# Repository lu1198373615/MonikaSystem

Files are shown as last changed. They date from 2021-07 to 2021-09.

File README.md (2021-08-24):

# 【原创新型】可以与树莓派合体的FPGA开发板
原因GitHub卡顿太严重。所以这个仓库已经搬到gitee了     
请前往[同名Gitee仓库](https://gitee.com/lu1198373615/MonikaSystem) 查看最新版       
想要板子的话可以直接拿gerber文件夹光绘文件打样，但开发板为本仓库创建者原创，仅供大家学习和交流，转载请注明出处。       
## 写在前面
树莓派拥有全球最大的开源硬件社区；FPGA逻辑资源丰富、IO众多且设计灵活；而高速AD和高速DA是实现信号发生器、示波器和软件无线电系统不可缺少的基本器件。
然而，树莓派社区缺少兼容性较好的FPGA开发板；此外，树莓派采用非实时操作系统，无法为高速AD、高速DA提供时钟驱动；
针对这些问题，本仓库开源一种新颖的配置了高速AD和高速DA的FPGA开发板，板上40pin扩展口可以与树莓派4b完美兼容，单板成本￥300左右。   
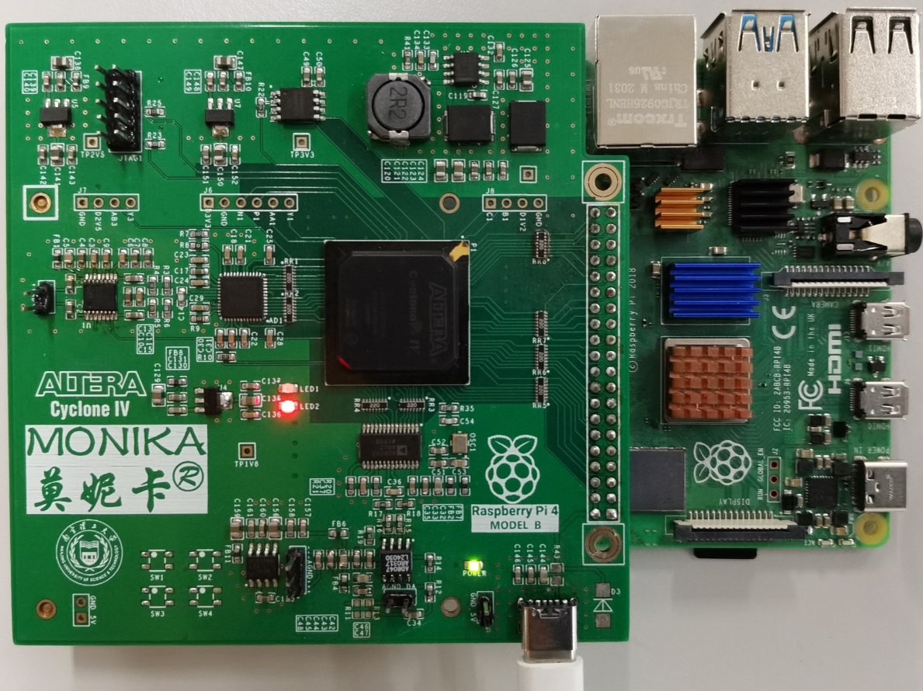
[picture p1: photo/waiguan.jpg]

    
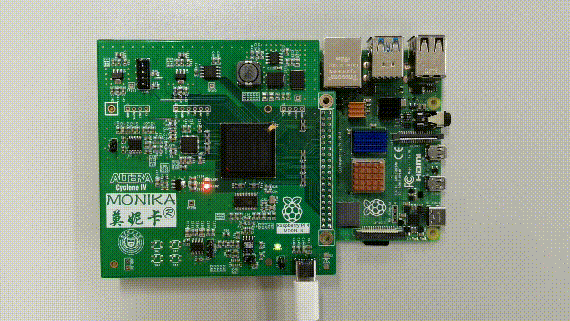
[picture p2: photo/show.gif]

    
## 介绍视频
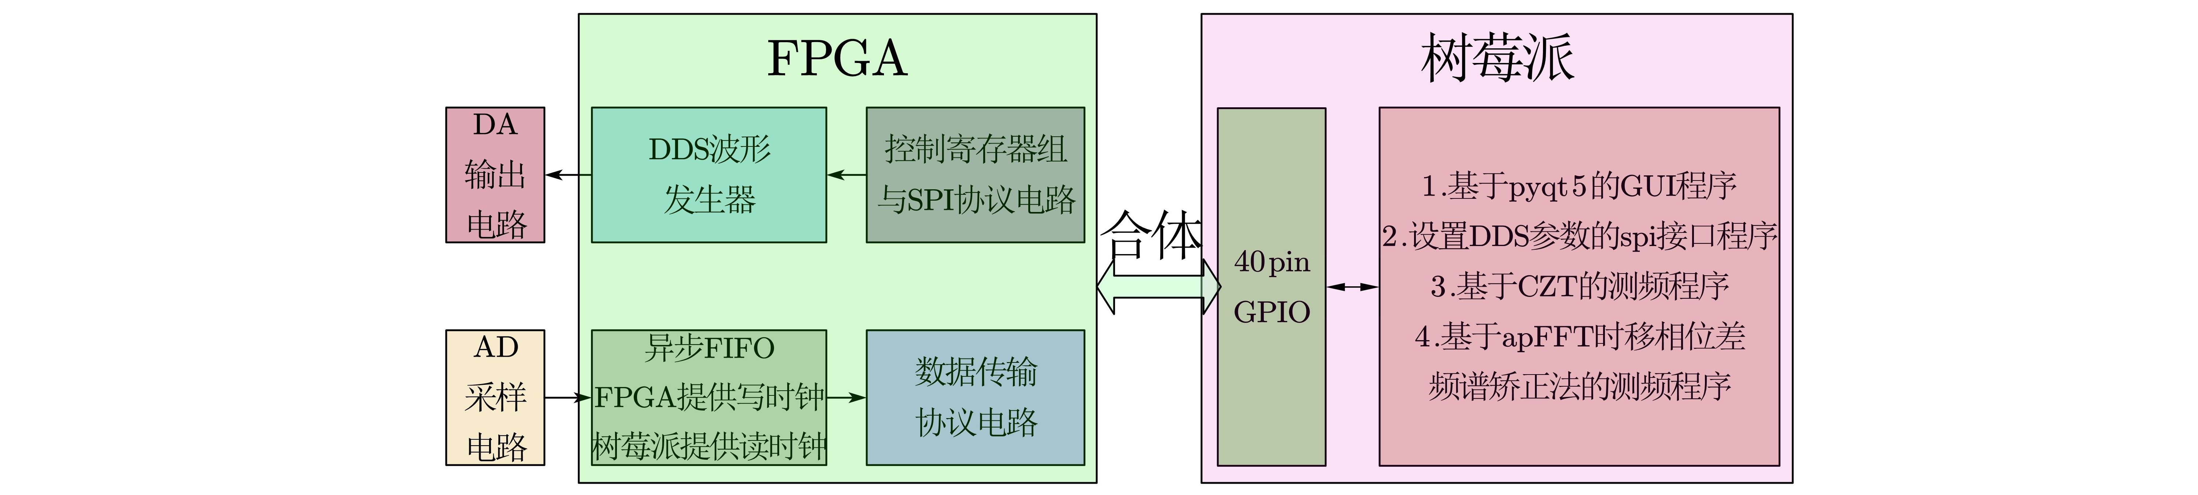
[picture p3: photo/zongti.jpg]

    
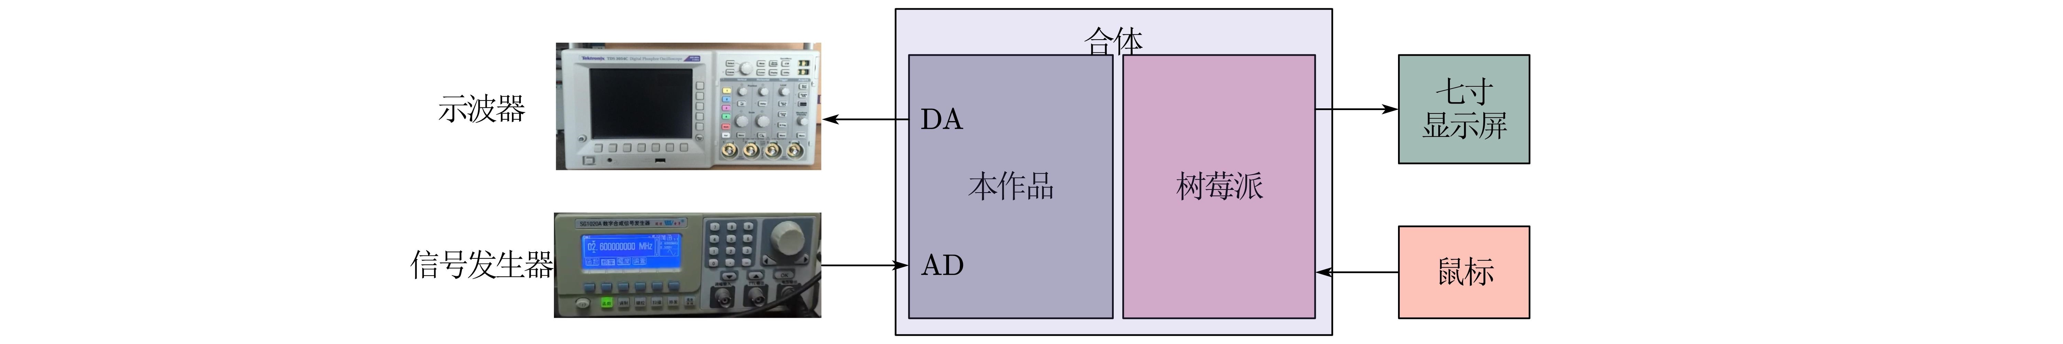
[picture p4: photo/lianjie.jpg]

    
鄙人把[介绍视频](https://www.bilibili.com/video/BV1644y1q7s1/) 放在了B站。     
视频拍摄场景：把本作品和树莓派合体后，DA输出端连接示波器，AD输入端接信号发生器，如上图所示。
用鼠标操作运行在树莓派的基于pyqt5的GUI程序，可以随意改变DA输出的波形，可以对信号发生器送入AD的信号进行显示和频率测量。     
## 工具与依赖项
+ 电路板制作      
Cadence套件：使用OrCAD绘制原理图、使用Allegro绘制PCB     
焊接时采用钢网刷锡和回流焊机     
+ FPGA端程序设计       
Altera公司工具：Quartus Primer 17.1、Modelsim-Altera、SignalTab等       
+ 树莓派端程序设计      
Python 3.x，用到的pypi库包括但不限于`pyqt5`、`matplotlib`、`numpy`       
操作GPIO用的是`wiringPi-Python`包，底层的`wiringpi.c`文件需要稍作修改：[修改说明](https://github.com/lu1198373615/MonikaSystem/blob/master/MODIFY.md)。
## 技术介绍
+ [硬件篇--自制FPGA开发板介绍](https://github.com/lu1198373615/MonikaSystem/blob/master/HARDWARE.MD)   
_（↑↑↑点击标题可查看↑↑↑）_    
_（这一部分依次讲解了外形尺寸设计、芯片选型原理图设计、电路板制作与测试。在芯片选型与原理图设计部分主要讲解了FPGA、电源、ADC和DAC电路，电源着重介绍DCDC电感电容值选型公式，ADC电路介绍差分放大器到ADC间共模电压的添加方式。电路板在深圳嘉立创完成打样，在学校实验室完成焊接和测试。约3500字，共20张图。）_    
+ [软件篇--“所见即所得”的任意波形发生器设计](https://github.com/lu1198373615/MonikaSystem/blob/master/SIGNALGENERATOR.md)    
_（↑↑↑点击标题可查看↑↑↑）_    
_（已经写完了，内容主要包括通过gif图片来展示程序功能，并描述如何利用DDS和SPI来实现这些功能。约1300字，13张图。）_    
+ [软件篇--示波器设计与频率测量算法](https://github.com/lu1198373615/MonikaSystem/blob/master/OSCILLOSCOPE.md)    
_（已经写完了，本部分展示了波形显示和频率测量的效果图，并介绍原理和实现方法。约1100字，共24图。）_    
+ 以上的信号发生器和示波器功能只是本开发板的示例程序，如果您有好的创意，欢迎补充：可以提issue，也可以直接在下方评论。     
_（期待您的程序为本开发板增加功能哦(づ￣ 3￣)づ）_     

## 附录

+ [小测试--树莓派4B使用wiringpi操作GPIO的速度](https://github.com/lu1198373615/MonikaSystem/blob/master/time_of_wiringpi.md)    

# 完结，撒花~~~

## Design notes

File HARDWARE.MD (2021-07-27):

## 序言
这一部分依次讲解了外形尺寸设计、芯片选型与原理图设计、电路板制作与测试。
在芯片选型与原理图设计部分主要讲解了FPGA、电源、AD和DA电路，电源着重介绍DCDC电感电容值选型公式，ADC电路介绍差分放大器到ADC间共模电压的添加方式。
电路板在深圳嘉立创完成打样，在学校实验室完成焊接和测试。约3500字，共20张图。     
## 外形尺寸设计
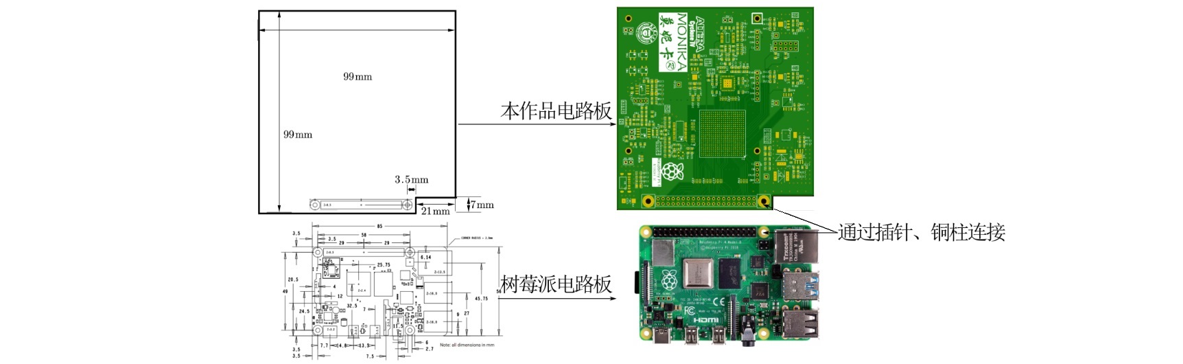
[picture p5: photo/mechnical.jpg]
   
    
电路板外形尺寸设计如上图。   
本作品设计初衷是为树莓派配套FPGA开发板，因此应预留40pin IO口与树莓派连接。   
大多数PCB打样厂家，单板边长100mm是价格的分水岭：
捷多邦99\*99mm的四层板是￥200/10pcs，而101\*101mm的四层板是￥439/10pcs；
华秋电路99\*99mm的四层板是￥199/10pcs，而101\*101mm的四层板是￥370/10pcs；
深圳嘉立创99\*99mm的四层板是￥80/10pcs，而101\*101mm的四层板是￥271.4/10pcs；
（价格查询时间：2021年6月20日晚上）。
因此本作品主体是99mm的正方形，这样可以享受最大的性价比。   
此外，本作品设计之初就考虑到树莓派4b的以太网口可能会挡到插针的连接，因此留了个7\*21mm的缺口。
（以太网：？？？我挡路了？？？）   

## 芯片选型与原理图设计
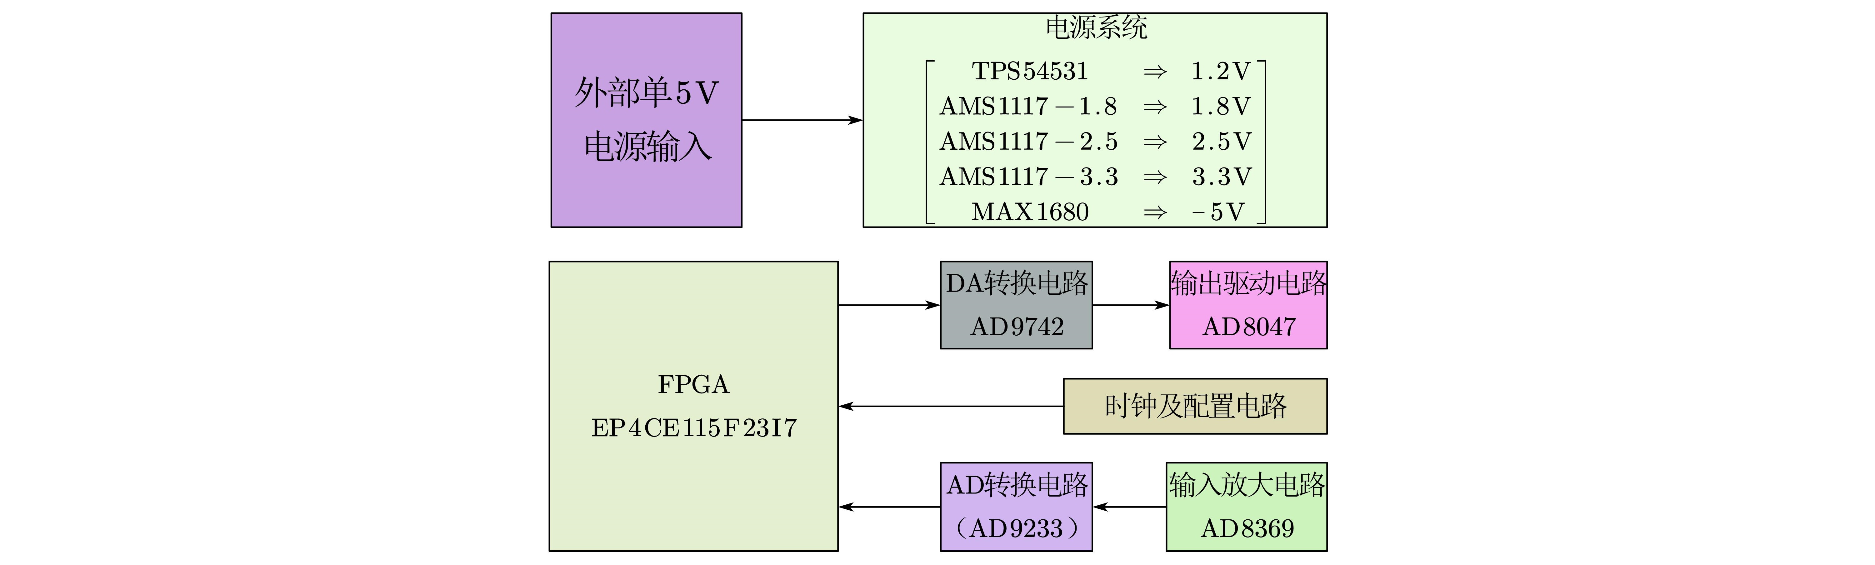
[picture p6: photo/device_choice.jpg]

    
### FPGA选型与设计
FPGA刚问世时价格昂贵，但近年来逐渐平民化。
其中，论性价比当吹Altera Cyclone IV E系列的EP4CE115F23I7N芯片，其资源如下：   
|  Logic elements (LEs)  |  Embedded memory  |  Embedded 18 × 18 multipliers  |  General-purpose PLLs  |  Global Clock Networks  |  User I/O Banks |  Maximum user I/O |
|  :----:  |  :----:  |  :----:  |  :----:  |  :----:  |  :----:  |  :----:  |
|  114480  |  3888  |  266  |  4  |  20  |  8  |  528  |

目前，桃bao店“深圳市叶恒科技”该芯片售价仅￥110（2021年6月20日晚上看是￥110，我记得前段时间看还是￥95来着，看来最近芯片确实都在涨价）。   
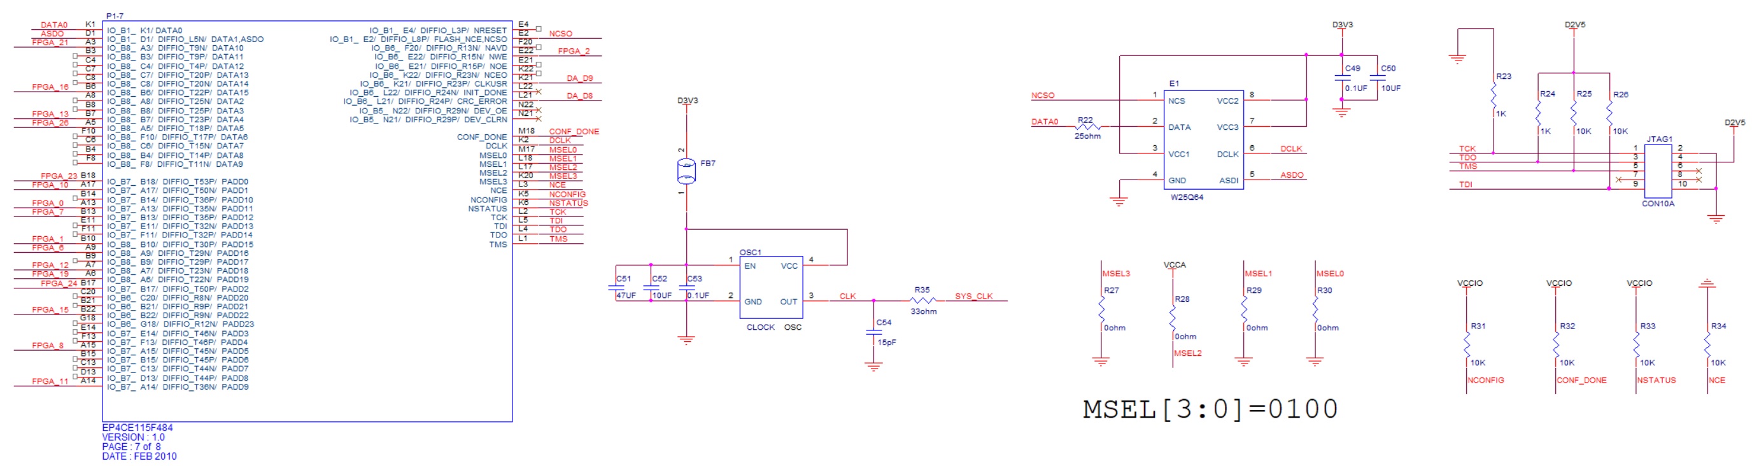
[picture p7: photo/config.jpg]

    
上图是FPGA的JTAG下载电路、FPGA配置电路以及时钟晶振电路，配置用的SPI_FLASH选用winbond公司的W25Q64芯片。   
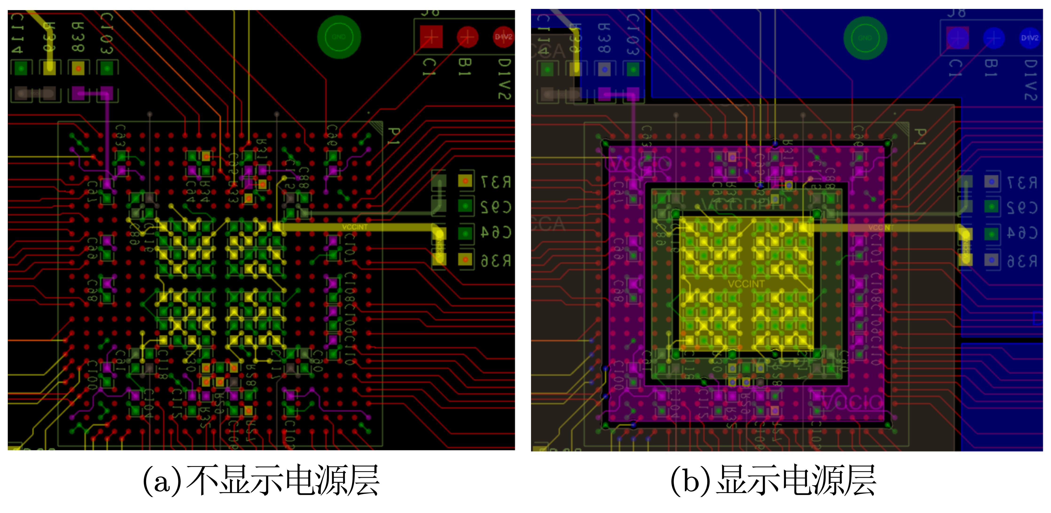
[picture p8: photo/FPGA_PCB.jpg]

    
上图是FPGA的layout部分，通过0&ohm;电阻对FPGA馈电有利于电路板调试；通孔打在去耦电容焊盘上，去耦电容全部放在电路板背面，有利于最小化EMI。
FPGA背面的0402电容的两焊盘间距0.5mm，FPGA的bga484封装焊盘间距也是0.5mm，在做BGA管脚扇出时特别方便。    
### 电源选型与设计
本作品供电方案拟选定TypeC供电，我是在桃bao店“risym”选的下面这种TypeC母座：   
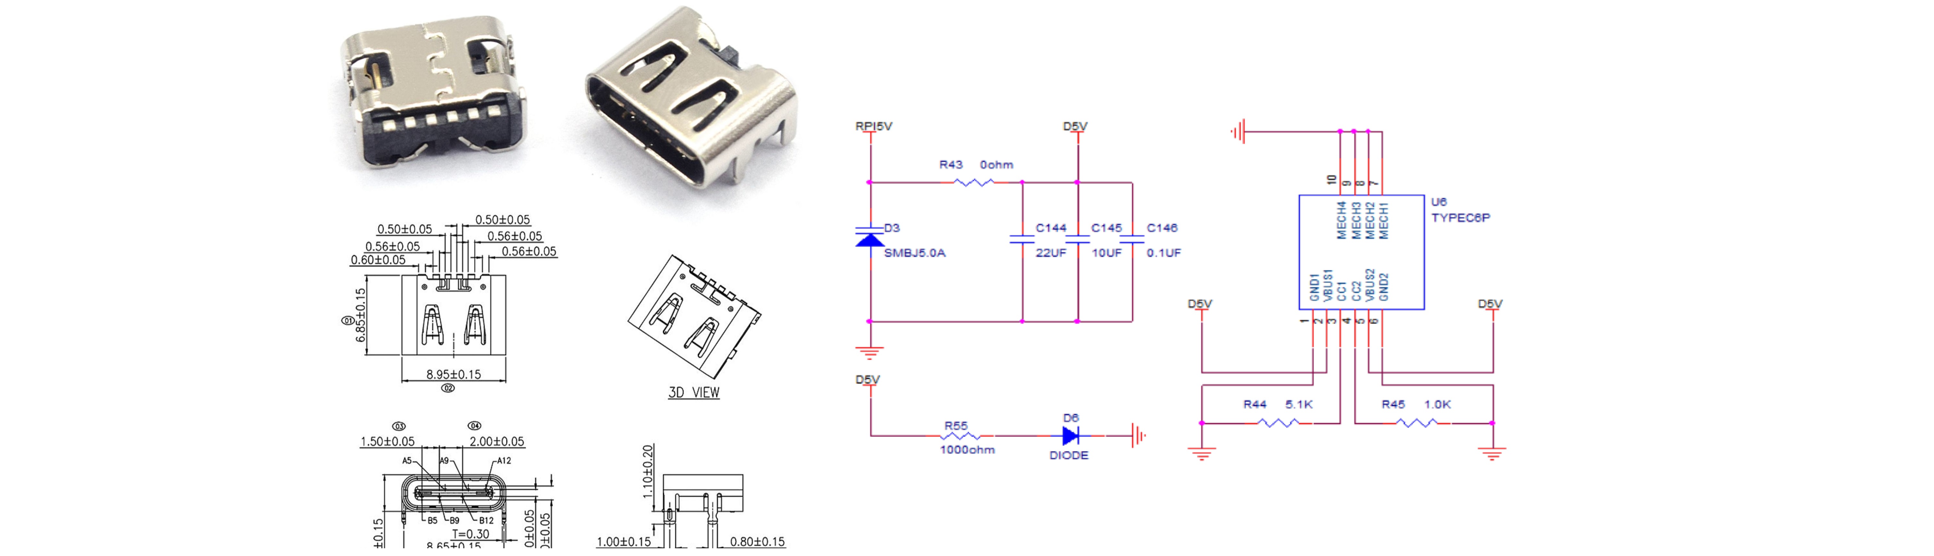
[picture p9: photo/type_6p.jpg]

    
[TypeC母座链接](https://detail.tmall.com/item.htm?id=580366058155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)     
只有6个贴片脚，依次是：GND1 VBUS1 c1 c2 VBUS2 GND2；4个机械插针脚不与任何贴片脚短路（我用万用表测的）。
画原理图时，机械插针脚可以接地（我就给它们接地了，可用），贴片脚VBUS1和VBUS2输出5.1V，c1和c2通过R44、R55这两个1k欧姆电阻接地可以诱骗PD快充（5伏3安）。
焊接时，如果只焊贴片脚不焊机械插针脚，容易在插拔时把锡弄断导致TypeC脱落（我就拔掉过...），所以最好把机械插针脚也焊上。      
树莓派4b的5V针脚和5V电源是直连的，因此焊接上0欧姆电阻R43使从树莓派来的RPI_5V和本作品电源D5V短接，可以让树莓派来给本作品供电，或让本作品的TypeC通过GPIO给树莓派供电。
无论通过哪种方式上电，插上插针后，本作品的地和树莓派4b的地都是短接的。无论通过哪种方式供电，电源指示灯D6都会在上电后亮起。    
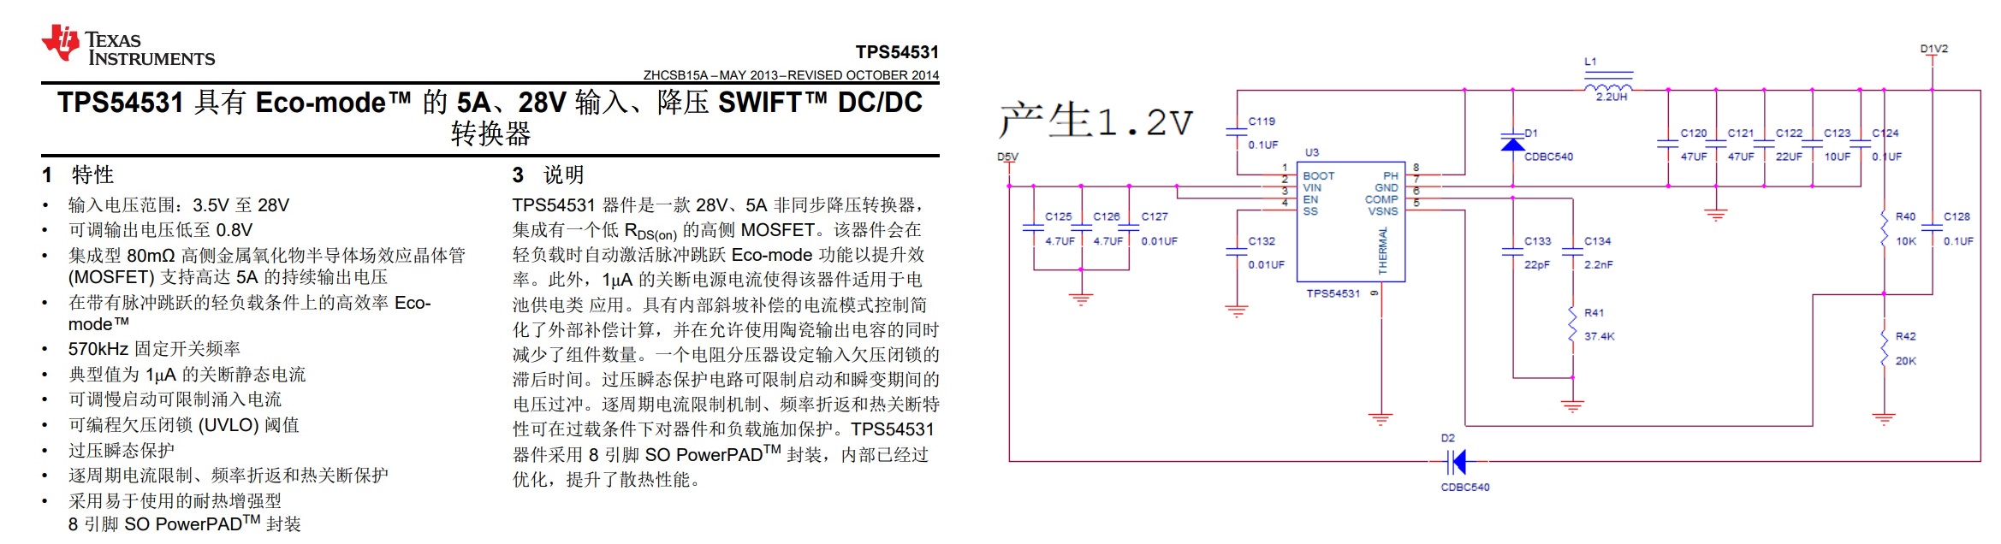
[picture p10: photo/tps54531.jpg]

    
[TPS54531数据表](https://www.ti.com.cn/cn/lit/ds/symlink/tps54531.pdf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)     
在电源转换器芯片选择时，考虑到给FPGA内核供电的1.2V电源会需要较大电流，因此选择tps54531这一DCDC电源芯片。
这款非同步DCDC输入电压范围较宽（3.5V~28V），最高输出电流5A，输出电压可编程，内部集成MOS，因此只需在外部配置功率电感、续流二极管和滤波电容即可。     
上图是tps54531的电路原理图，D1就是所谓续流二极管，在tps54531内部的MOS管导通时，续流二极管截止，电感电流呈线性上升；
当Q1截止时，电感电流不能突变，经过续流二极管(忽略二极管的导通压降)形成回路，给输出负载供电。     
电感值的选择公式为     
$$
L_{MIN} = \frac{V_{OUT} \times (V_{IN(MAX)} - V_{OUT})}{V_{IN(MAX)} \times K_{IND} \times I_{OUT} \times f_{sw}}
$$
TPS54531的开关频率是570kHz，FPGA内核最多需要3.5A电流，因此
$$
V_{OUT}=1.2V，V_{IN(MAX)}=5V，f_{sw}=570kHz，K_{IND}=0.2，I_{OUT}=3.5A
$$
于是计算出电感值选取2.2&mu;H。    
此时流过电感的纹波电流为：
$$
I_{ripple} = \frac{V_{OUT} \times (V_{IN(MAX)} - V_{OUT})}{V_{IN(MAX)} \times L_{OUT} \times f_{sw} \times 0.8}=0.875A
$$
于是流过电感总电流为
$$
I_{L(RMS)} = \sqrt{I_{OUT}^2 + \frac{1}{12} \times I_{ripple}^2}=3.509A
$$
流过电感峰值电流为
$$
I_{L(peak)} = I_{OUT} + \frac{1}{2} \times I_{ripple}=3.9375A
$$
本作品选择的电感型号是CDRH104R可以承受7.5A电流，满足条件。    
如果说电感的选取决定了DCDC的纹波电流，那么电容的选取将决定纹波电压。一方面，应考虑瞬态负载响应和输出电压纹波来选取容值，另一方面，最大串联等效电阻ESR必须符合以下公式
$$
R_{ESR} < \frac{V_{OUTripple}}{I_{ripple}}
$$
瞬态负载响应电容器指的是当负载电流发生变化时，电容器的储能必须保证至少两个DCDC时钟周期输出电压在可容忍范围，我们认为，当电流波动50%时，要求电压波动在5%以内。于是参数选取如下
$$
\Delta I_{OUT}=0.5 \times I_{OUT}=1.75A，\Delta V_{OUT}=0.05 \times V_{OUT}=0.06V
$$
于是，瞬态负载响应电容量公式为
$$
C_{O1} = \frac{2 \times \Delta I_{OUT}}{{f_{sw} \times \Delta V_{OUT}}}\approx102.3\mu F
$$
本作品希望1.2V电源纹波在10mV以内，因此纹波电容选取
$$
C_{O2} = \frac{1}{8 \times f_{sw}} \times \frac{1}{R_{ESR}}=\frac{1}{8 \times f_{sw}} \times \frac{1}{\frac{V_{OUTripple}}{I_{ripple}}}\approx19.2\mu F
$$
于是    
$$
C_O = C_{O1} + C_{O2} \approx121.5\mu F
$$
本作品使用两只47&mu;F、一只22&mu;F、一只10&mu;F和一只0.1&mu;F的陶瓷电容器，容值共126.1&mu;F满足要求。
此外，多只电容并联使用将有助于减小ESR和增加电压转换器滤波电路极点数量。     
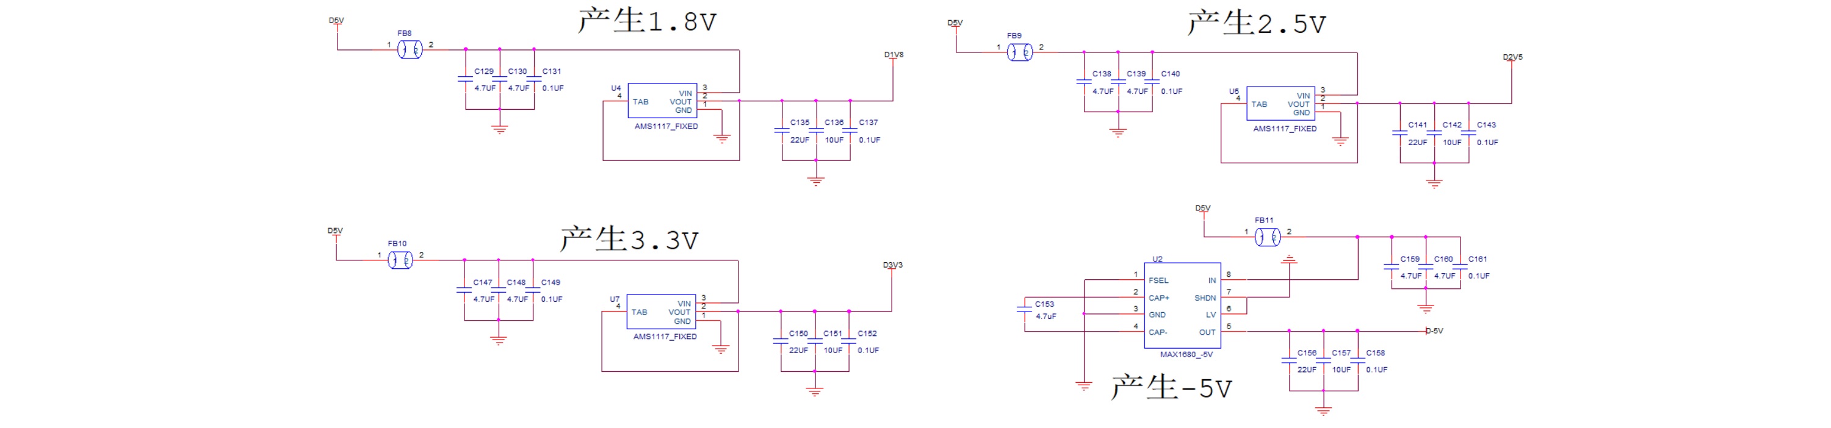
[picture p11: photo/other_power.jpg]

    
除了1.2V以外，电路板还需要3.3V用于VCCIO、2.5V用于FPGA中模拟锁相环的供电、1.8V用于AD9233的供电（AD9233将在模拟信号输入电路中讲解）。这些电源都使用SOT89封装AMS1117（一款低成本、小封装LDO电源来解决）。-5V电源则选用MAX1680。    

### 模拟输入电路选型与设计
模拟输入电路指外界模拟信号经差分放大和AD转换后，以数字信号的形式进入FPGA的过程。    
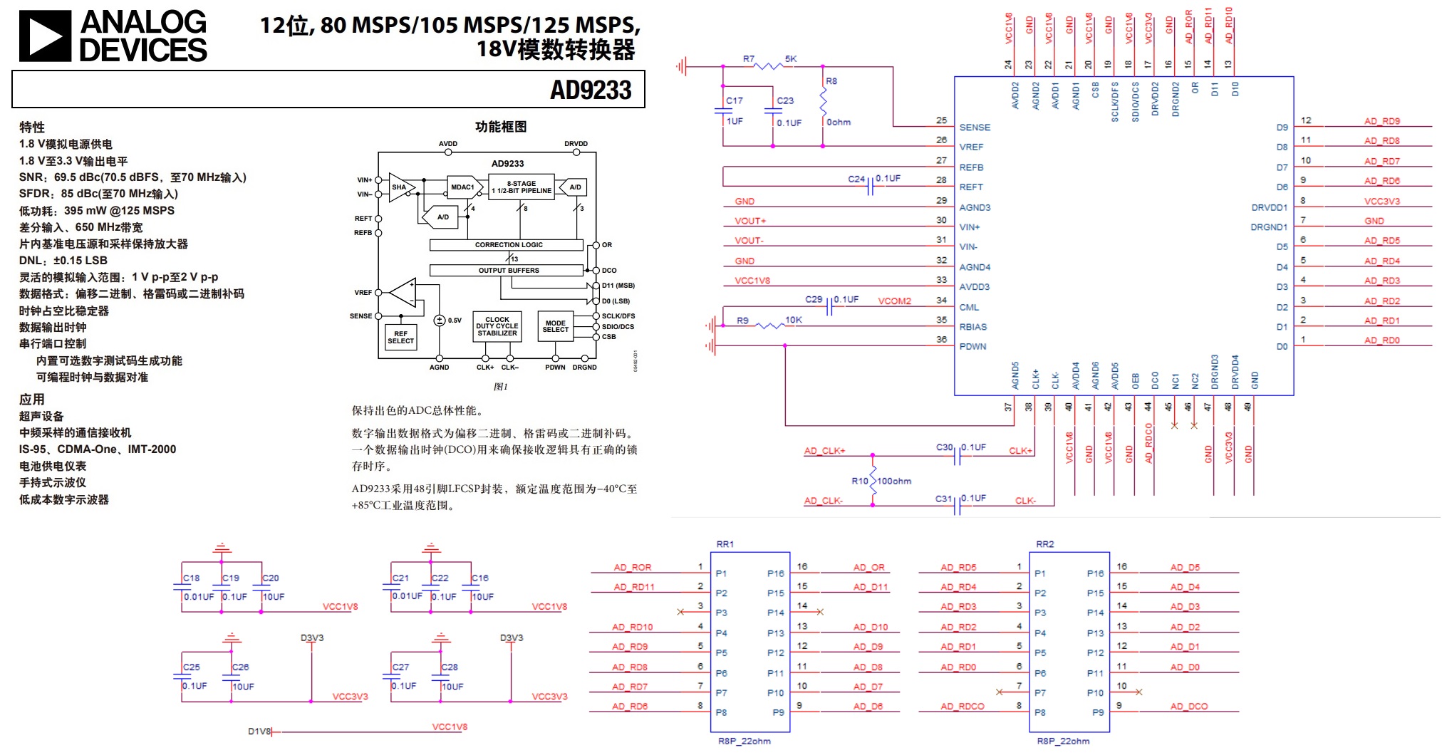
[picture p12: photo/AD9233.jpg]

    
[AD9233数据表](https://www.analog.com/media/cn/technical-documentation/data-sheets/AD9233_cn.pdf)     
本作品选择ADI公司的12位AD转换器AD9233作为从模拟信号到数字信号的转换器。上图是AD9233数据表的扉页和本作品绘制的原理图，模拟信号通过AD9233的30和31脚差分进入，转化成数字量后通过22欧姆排阻RR1、RR2进入FPGA。    
AD9233的数字信号输出电平由DVDD提供，本作品取DVDD=3.3V。
AD9233架构由一个前端采样保持放大器(SHA)和其后的流水线型开关电容ADC组成。各个级的量化输出组合在一起，在数字校正逻辑条件下最终形成一个12位转换结果。
转换参考电压由芯片内部提供，这一切的供电由模拟1.8V供电提供支持。此外，高速、高分辨率ADC对时钟输入信号的质量非常敏感。在给定的输入频率 $ F_{IN} $ 下，由于抖动 $ t_j $ 造成的信噪比(SNR)下降计算公式如下
$$
SNR = -20log(2\pi \times F_{IN} \times t_j)
$$
当孔径抖动可能影响AD9233的动态范围时，应将时钟输入信号视为模拟信号。时钟驱动器电源应与ADC输出驱动器电源分离，以免在时钟信号内混入数字噪声。万幸，AD9233的等效时钟输入电路是由1.8V模拟AVDD供电的，与数字部分完全独立。    
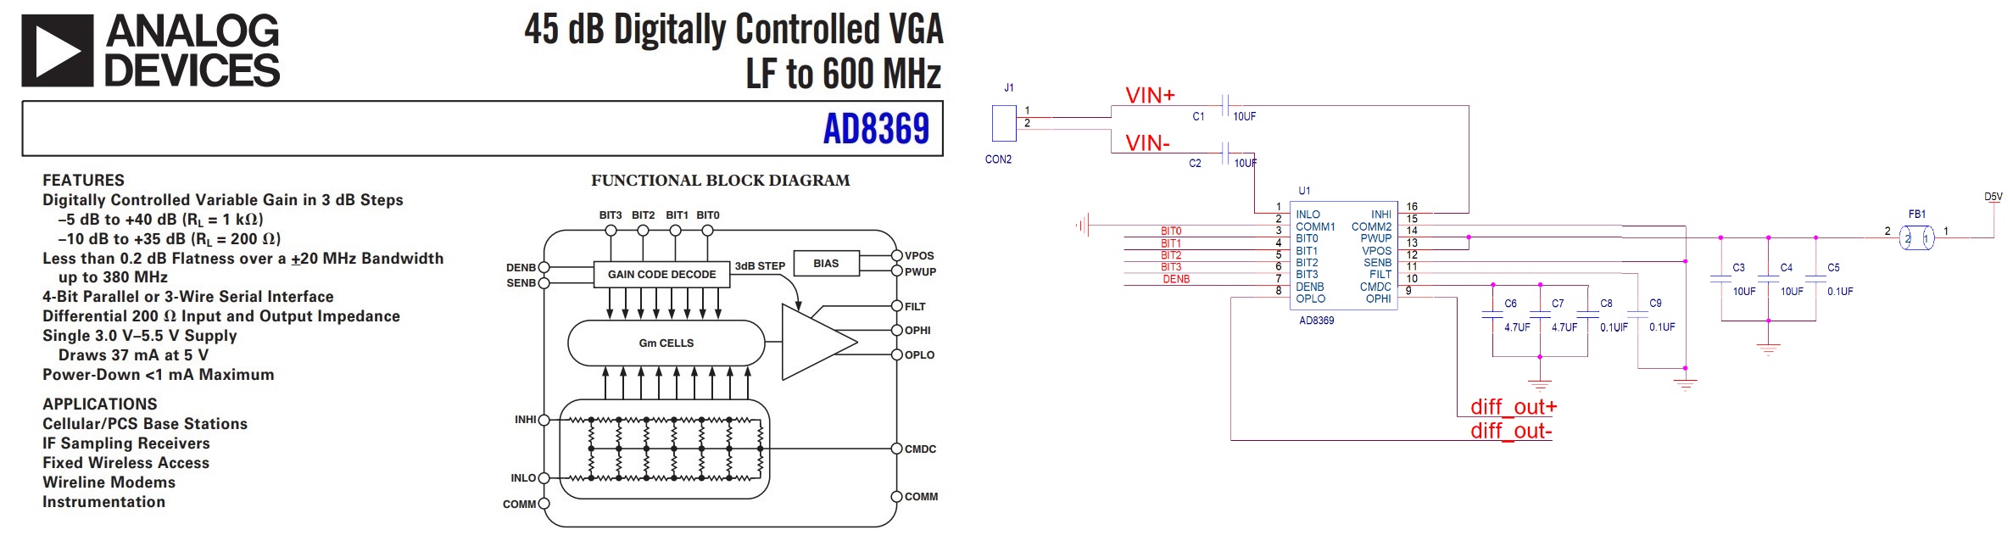
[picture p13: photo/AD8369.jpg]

    
[AD8369数据表](https://www.analog.com/media/en/technical-documentation/data-sheets/AD8369.pdf)     
为了提供足够的驱动电流和提高模拟信号的电压输入范围，本作品选择AD8369用于模拟信号的差分放大。
上图是AD8369数据表扉页和我为其绘制的原理图。
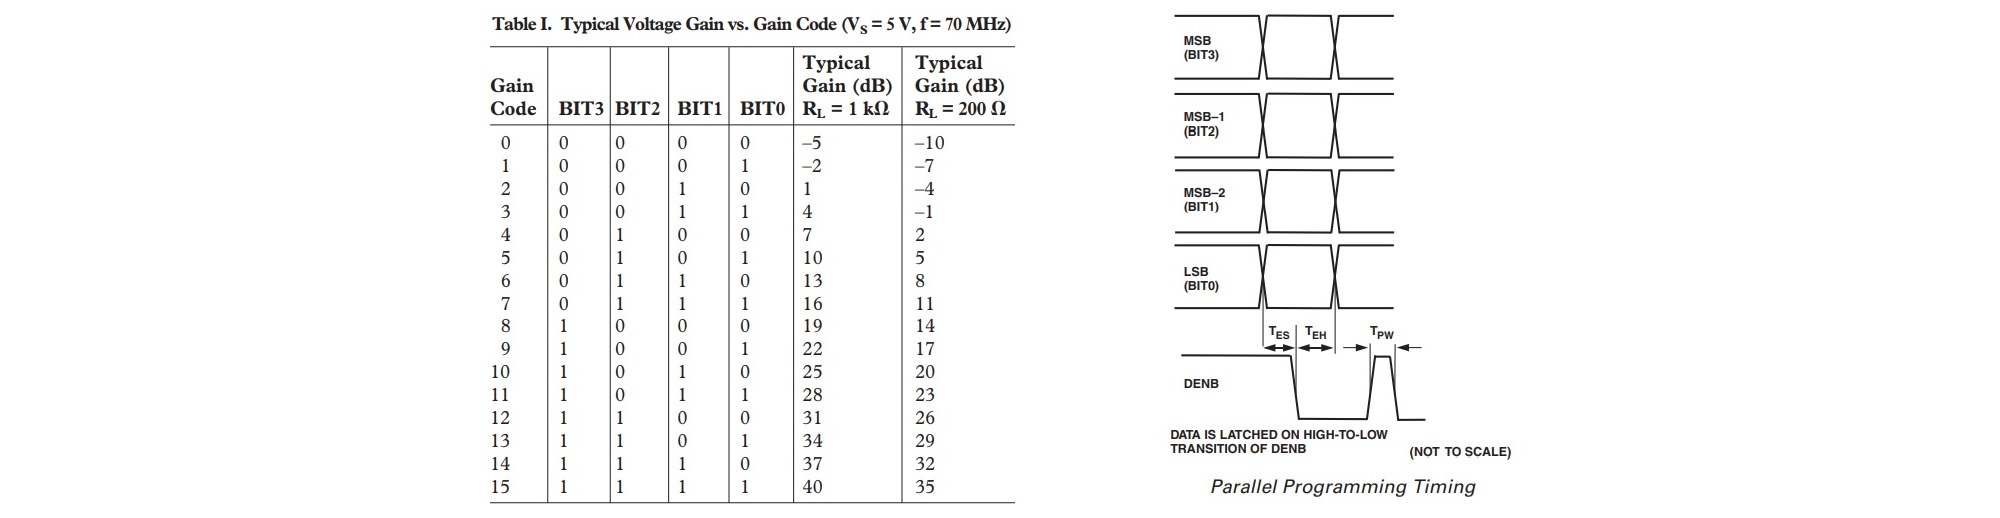
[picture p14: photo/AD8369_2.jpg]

    
AD8369作为一款完全由数字电路控制的-5\~40dB可变增益放大器，它的增益由BIT3\~BIT0决定。
上图是增益与BIT3\~BIT0取值的关系，以及时序图。时序图表明，在DENB的下降沿，BIT3\~BIT0的电平被锁存，经译码后控制电阻加权网络实现增益控制。
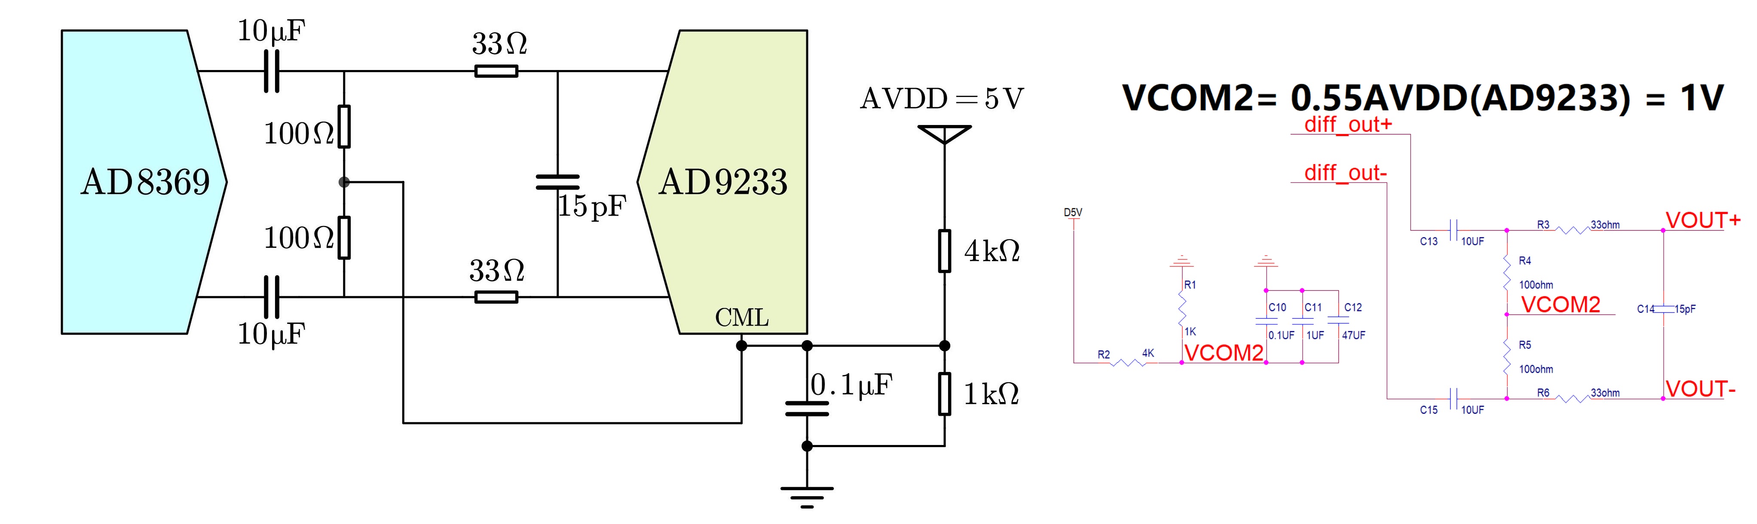
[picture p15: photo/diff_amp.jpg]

    
AD9233的CML共模电压输入 $ V_{CM}=0.55 \times AVDD $ 时才能获得最佳性能，AVDD=1.8V，因此 $ V_{CM} $ 可由4k&ohm;和1k&ohm;电阻分压产生1V电压并送入AD9233的CML脚。    
另一方面，AD8369对差分输入的信号放大后，差分输出的信号共模电压是电源电压和地的中点，在采用5V单电源给AD8369供电时，共模电压约2.5V。
于是，如上图所示，AD8369的差分输出电压经10&mu;F电容隔直后，经100&ohm;电阻添加共模电压，产生需要的输入，上图C13和C15起隔直作用，共模电压加在R4、R5中间。
R3、R6和C14共同组成了70MHz带宽的低通滤波器，用于输入信号的抗混叠滤波。
### 模拟输出电路选型与设计
模拟输出电路指的是，FPGA将数字量送入DA转换器，经差分转单端芯片转化为模拟量输出的过程。     
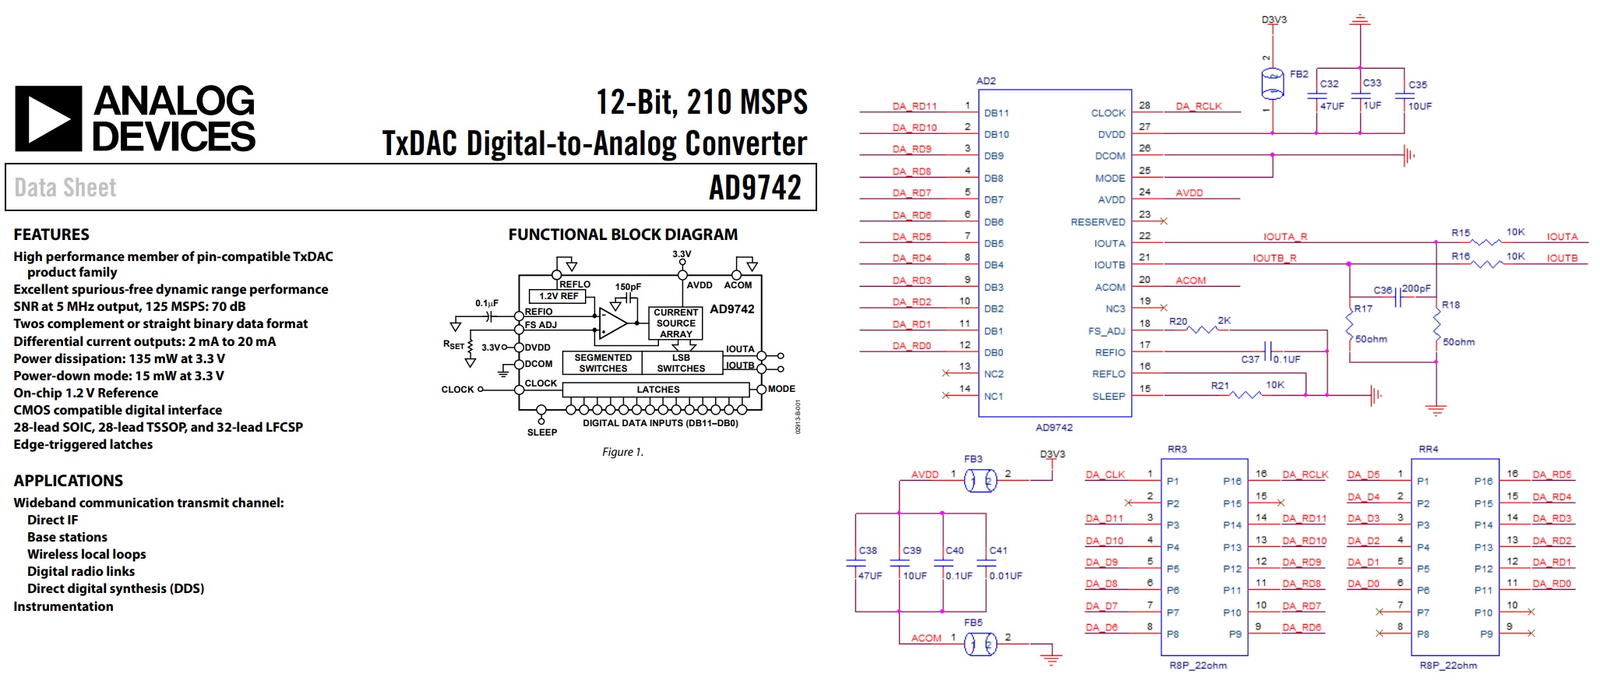
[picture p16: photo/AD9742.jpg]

    
[AD9742数据表](https://www.analog.com/media/en/technical-documentation/data-sheets/AD9742.pdf)     
上图是本作品选用的DA转换器AD9742的数据表扉页和原理图。AD9742是一款12bit、最高支持210MSPS的高速DA转换器，适用于直接中频、DDS和软件无线电等场合。     
FPGA输出的数字量经22&ohm;排阻限流后，进入AD9742，产生差分电压输出，按照手册，输出差分电压值是
$$
V_{DIFF} = ((2 \times DACCODE - 4095) / 4096) \times (32 \times R_{LOAD} / R_{SET}) \times V_{REFIO}
$$
其中，DACCODE是数字量输入，范围是0\~4095， $ R_{LOAD} $ 是输出负载电阻， $ R_{SET} $ 是FS_ADJ管脚连接的电阻。
从上图看，本作品取 $ R_{LOAD}=50 $ &ohm;，取 $ R_{SET}=2000 $ &ohm;，代入可计算出输出差分电压范围
$$
-0.96V < V_{DIFF}<0.96V
$$
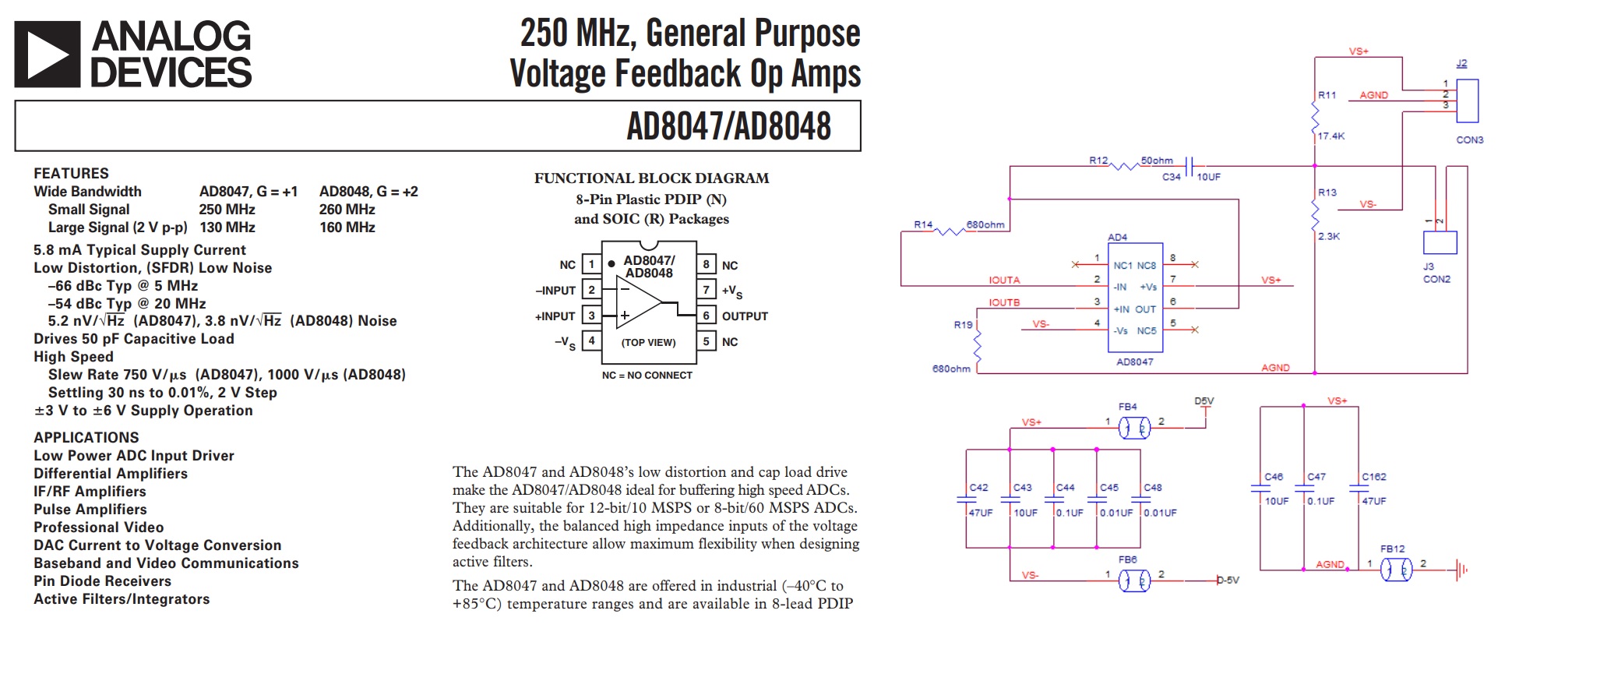
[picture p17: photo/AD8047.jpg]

    
[AD8047数据表](https://www.analog.com/media/en/technical-documentation/data-sheets/AD8047_8048.pdf)     
为了增加模拟量输出的驱动能力，本作品在DA转换器后面接了一个差分转单端放大器AD8047。该放大器增益可通过外部电阻控制，具有宽带高增益的优点。    
为了减小电源纹波对输出模拟信号信噪比的影响，本作品使用磁珠和电容制造了临时的干净电源，即VS+、VS-和AGND
## PCB绘制解析与电路板打样制作
PCB采用四层板，叠层如下：
+ L1: TOP Layer
+ L2: GND Layer
+ L3: POWER Layer
+ L4: BOTTOM Layer
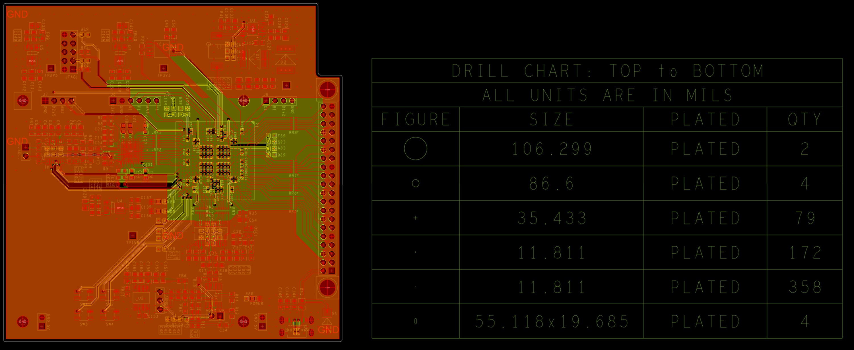
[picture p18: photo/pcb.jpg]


上图是原理图绘制->网表导入->布局->布线->铺铜->调整丝印生成钻孔->输出光绘，完成的PCB在Cadence Allegro中的样子。   
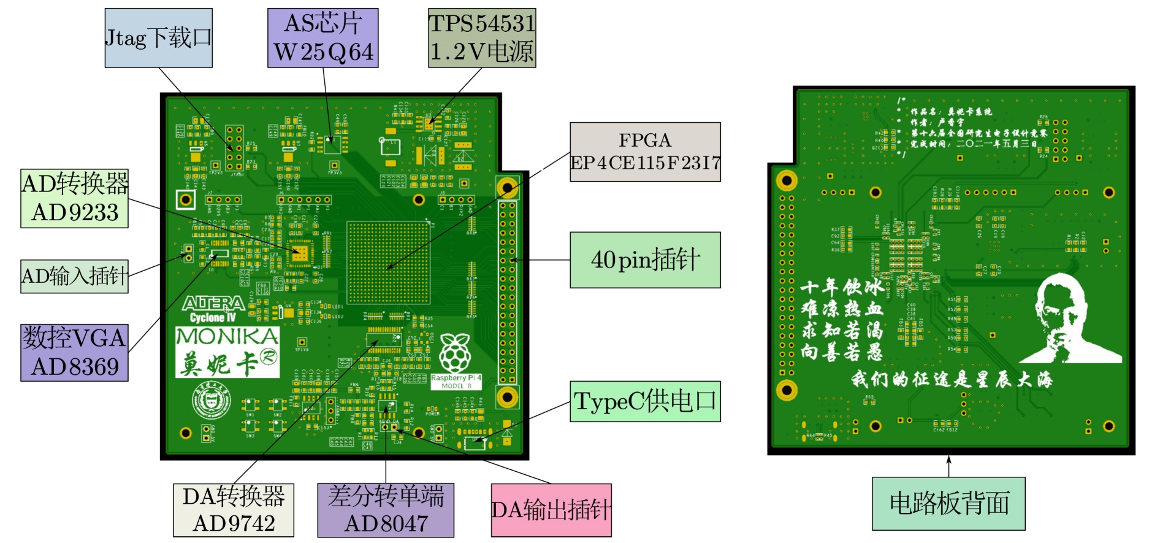
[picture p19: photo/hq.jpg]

    
Allegro不能像Altium Designer，可以根据3D封装直接仿真出成品图。但好在“华强PCB”的在线下单软件可以对光绘文件输出成品板仿真图像，如上图所示。
本作品还添加了一些丝印，正面有Altera Cyclone IV、Raspberry Pi 4 MODEL B、以及本作品开发板名称“莫妮卡”等；反面有一些作品名、作者、完成时间等字样。    
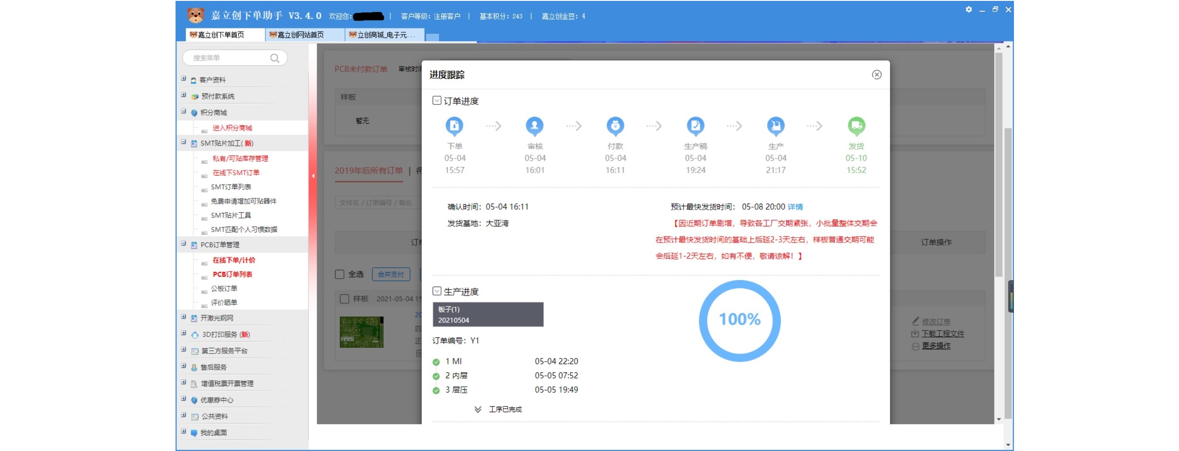
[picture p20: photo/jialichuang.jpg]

    
作品在深圳嘉立创完成打样（因为便宜），指定了TG值155的台湾南亚板材，四层板沉金加钢网10pcs共￥323.86，算是全网最低价了吧。
之后又经历了买芯片、等快递、回流焊接等工序，最终完成了电路板的制作。    
## 电路板功能测试
电路板测试主要包括Jtag、AS下载功能的测试和AD、DA功能测试。    

    
这是本仓库开头放的图，它显示了本作品如何与树莓派40pin插针连接；
此外，上图还展示了一个简易流水灯程序，流水灯程序可以通过Jtag方式下载，也可以通过转为.jic的文件后，以AS方式下载。这说明本作品Jtag、晶振、AS和LED功能正常。   
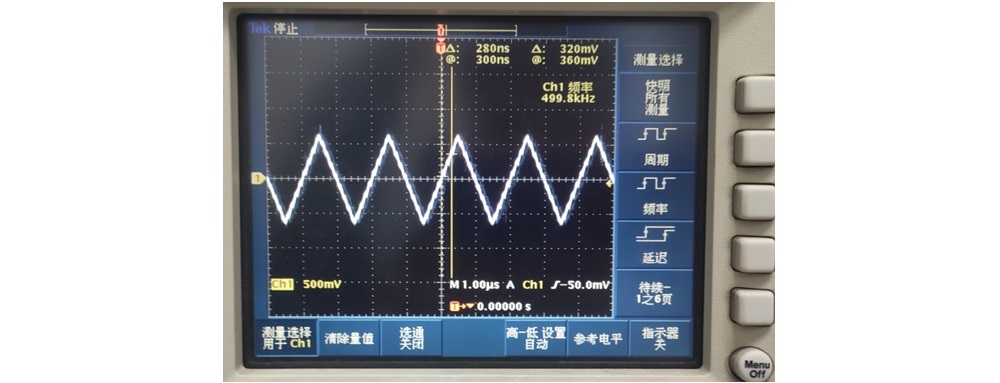
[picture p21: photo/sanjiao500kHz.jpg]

    
上图是本作品DA转换器生成的500kHz三角波在示波器上的图片，于是认为本作品模拟输出功能正常。
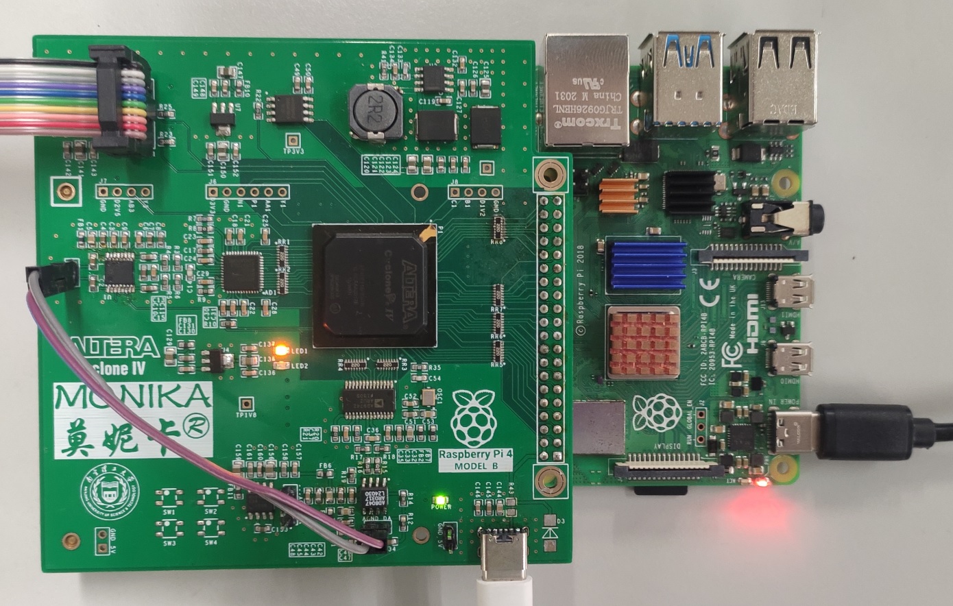
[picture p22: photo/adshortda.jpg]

    
为了对AD转换器功能测试，我用杜邦线短接AD和DA插针，把DA输出直接送进AD输入，如上图所示。
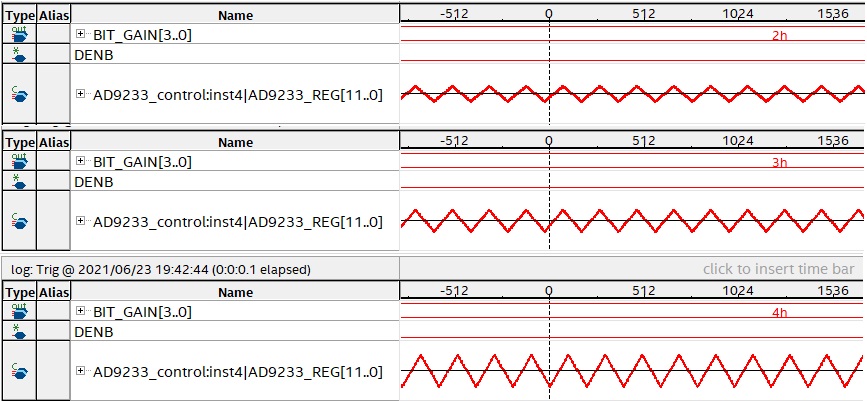
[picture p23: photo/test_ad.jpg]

    
在Quartus 17.1 Standard Edition的Signal Tab仿真器中，捕获并查看AD输入信号，于是得到了上图的测试结果。上图中，BIT_GAIN是差分放大器AD8369的增益，AD9233_REG是AD采样波形，很明显，AD采样波形也是三角波，且幅度随着BIT_GAIN的增大而增大。于是认为本作品AD和DA功能正常。

下一部分，[软件篇--“所见即所得”的任意波形发生器设计](https://github.com/lu1198373615/MonikaSystem/blob/master/SIGNALGENERATOR.md)

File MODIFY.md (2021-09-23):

其实就改了`wiringPi.c`文件里的一个函数。       

```c
unsigned int digitalReadByte (void)
{
  int pin, x ;
  uint32_t raw ;
  uint32_t data = 0 ;

  /**/ if (wiringPiMode == WPI_MODE_GPIO_SYS)
  {
    for (pin = 0 ; pin < 8 ; ++pin)
    {
      x = digitalRead (pinToGpio [pin]) ;
      data = (data << 1) | x ;
    }
  }
  else
  {
    raw = *(gpio + gpioToGPLEV [0]) ; // First bank for these pins
    for (pin = 0 ; pin < 8 ; ++pin)
    {
      x = pinToGpio [pin] ;
      data = (data << 1) | (((raw & (1 << x)) == 0) ? 0 : 1) ;
    }
  }
  return data ;
}
```

上面是 [原wiringPi-python包](https://github.com/WiringPi/WiringPi-Python) 的`unsigned int digitalReadByte (void)`函数，它读取wiringPi编码的0~7号管脚，并返回整形int数据类型。
在从FIFO里读取AD采样数据时，要求一次读12bit（AD9233是12位宽的模数转换器），因此改为下面的代码。      

```c
unsigned int digitalReadByte (void)
{
  int ret;
  ret = *(gpio + gpioToGPLEV [0]);
  return (ret & 127) + ((ret>>5) & 3968);// 3968=(2^12-1)-(2^7-1)
}
```

上面的函数是把BCM编码GPIO的0-6号和12-16设为AD转换结果的0~11位，即     
```verilog
assign AD_INPUT = {BCM[16:12],BCM[6:0]};
```

在安装`wiringPi-python`时，不使用`pip`的安装方式，而是先用`Git`下拉软件包：      

```shell
git clone --recursive https://github.com/WiringPi/WiringPi-Python.git
```

找到`wiringPi.c`里的`unsigned int digitalReadByte (void)`函数，手动替换，然后再安装：      

```shell
sudo apt install swig
sudo python3 setup.py install
```
即可。

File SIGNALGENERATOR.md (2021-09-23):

## 前言
已经写完了，内容主要包括通过gif图片来展示程序功能，并描述如何利用DDS和SPI来实现这些功能。约1300字，13张图。      

## 效果展示

    

    
鄙人把[介绍视频](https://www.bilibili.com/video/BV1644y1q7s1/) 放在了B站。     
视频拍摄场景：把本作品和树莓派合体后，DA输出端连接示波器，AD输入端接信号发生器，如上图所示。
用鼠标操作运行在树莓派的基于pyqt5的GUI程序，可以随意改变DA输出的波形，可以对信号发生器送入AD的信号进行显示和频率测量。     
### 生成250kHz正弦波、三角波、上/下扫频锯齿波在示波器显示
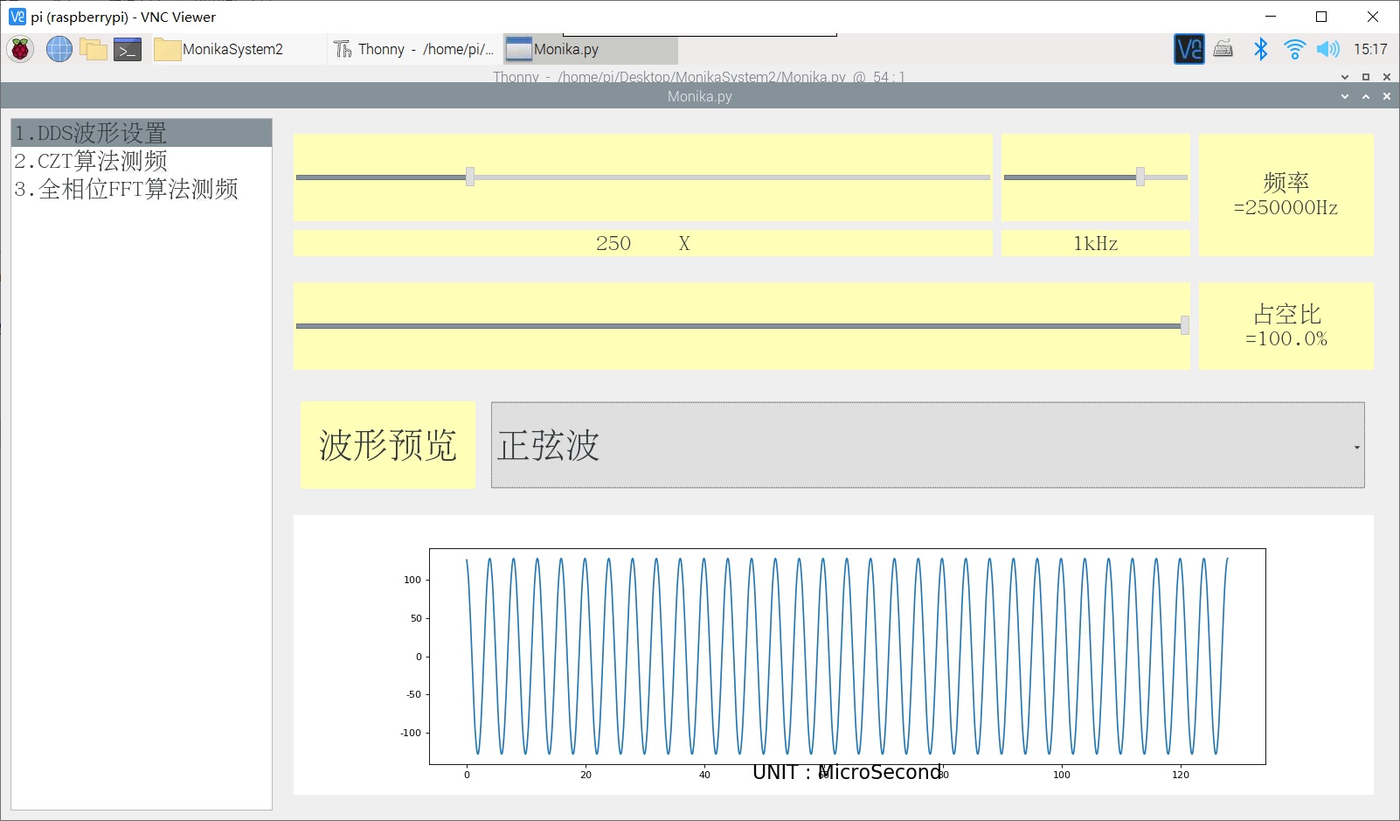
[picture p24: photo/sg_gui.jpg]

    
_以下gif内存大于1M，以游客身份查看时无法加载，建议登录后查看_    

    
（一边用鼠标操作GUI界面一边讲解）     
台词：现在是生成250kHz的正弦波...改为三角波...改为下扫频锯齿波...改为上扫频锯齿波...改回正弦波...     
### 生成715kHz正弦波并用示波器测量频率

    
（用鼠标拖动GUI控件调整频率，示波器上的正弦波频率随之改变，调为773kHz并按下示波器的measure，示波器显示出频率）     
台词：调节频率...现在GUI显示生成773kHz正弦波...然后...是773k。     
### 调节占空比（以三角波为例）

    
（用鼠标拖动GUI控件调整占空比，占空比调到6.25%，按示波器autoset，再把占空比调到50%，按示波器autoset，最后调回100%）     
台词：下面调节占空比三角波的占空比...现在占空比只有6.25%也就是十六分之一...然后把占空比调到50%看一看...现在占空比是50%。     
## 原理介绍

### 使用原理
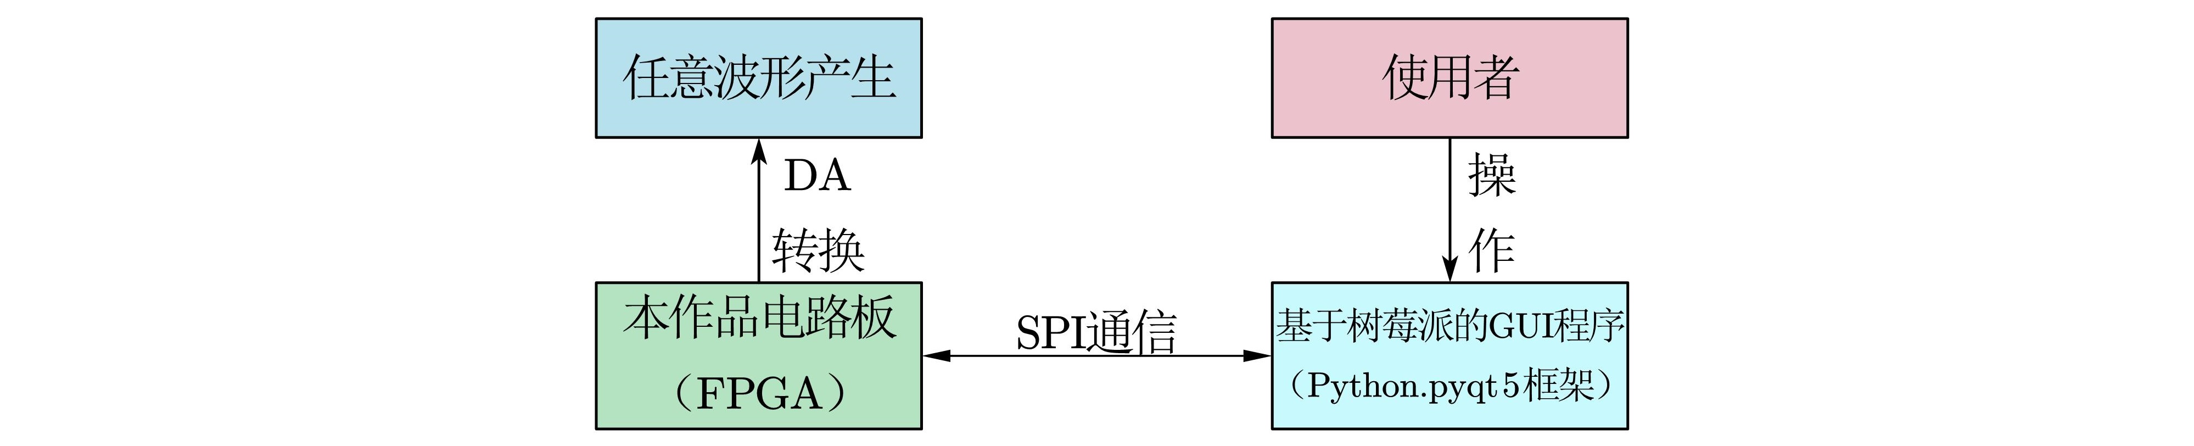
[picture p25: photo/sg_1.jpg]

    
### 总体原理
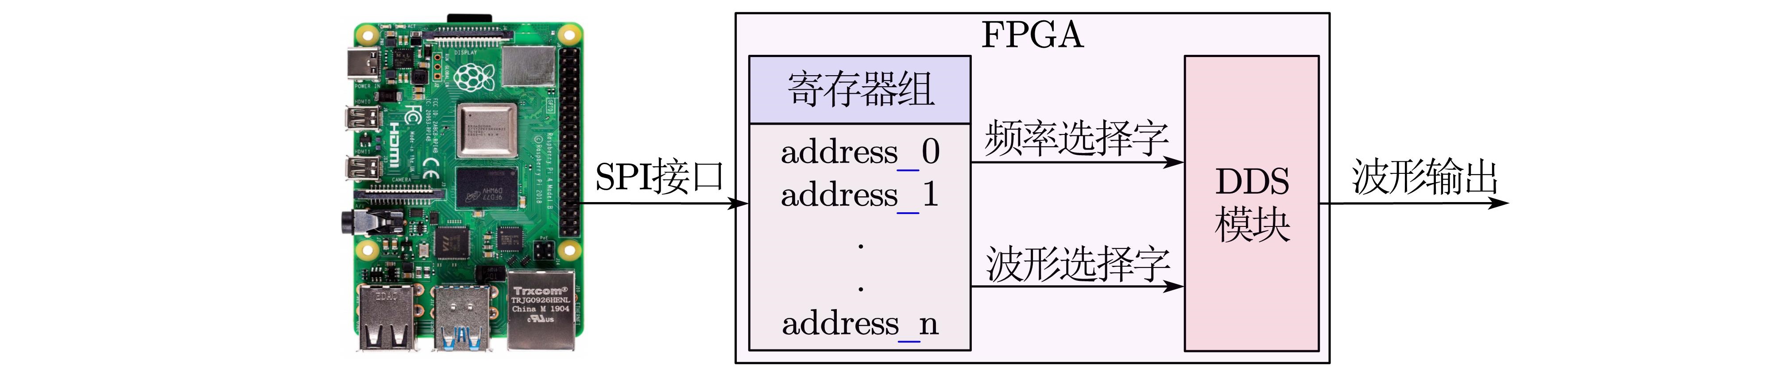
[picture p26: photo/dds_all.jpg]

    
树莓派通过SPI接口，每次向FPGA发送2个8bit信号，第一个8bit是寄存器的地址，
第二个8bit是寄存器的内容。寄存器的内容排列组合成频率控制字和波形选择字，
送入DDS模块后，实现查表和波形数据输出。
### DDS模块原理
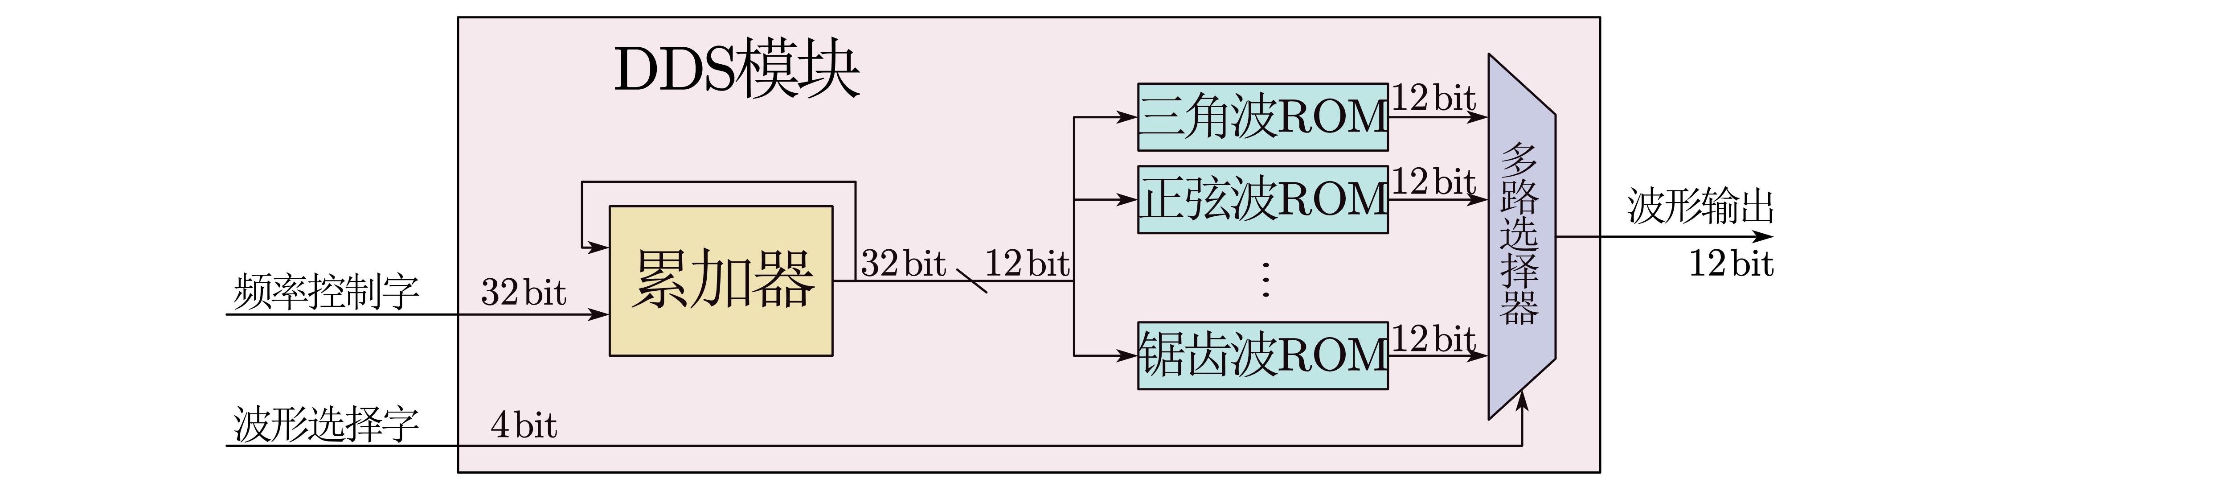
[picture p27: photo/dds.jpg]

    
### SPI接口原理
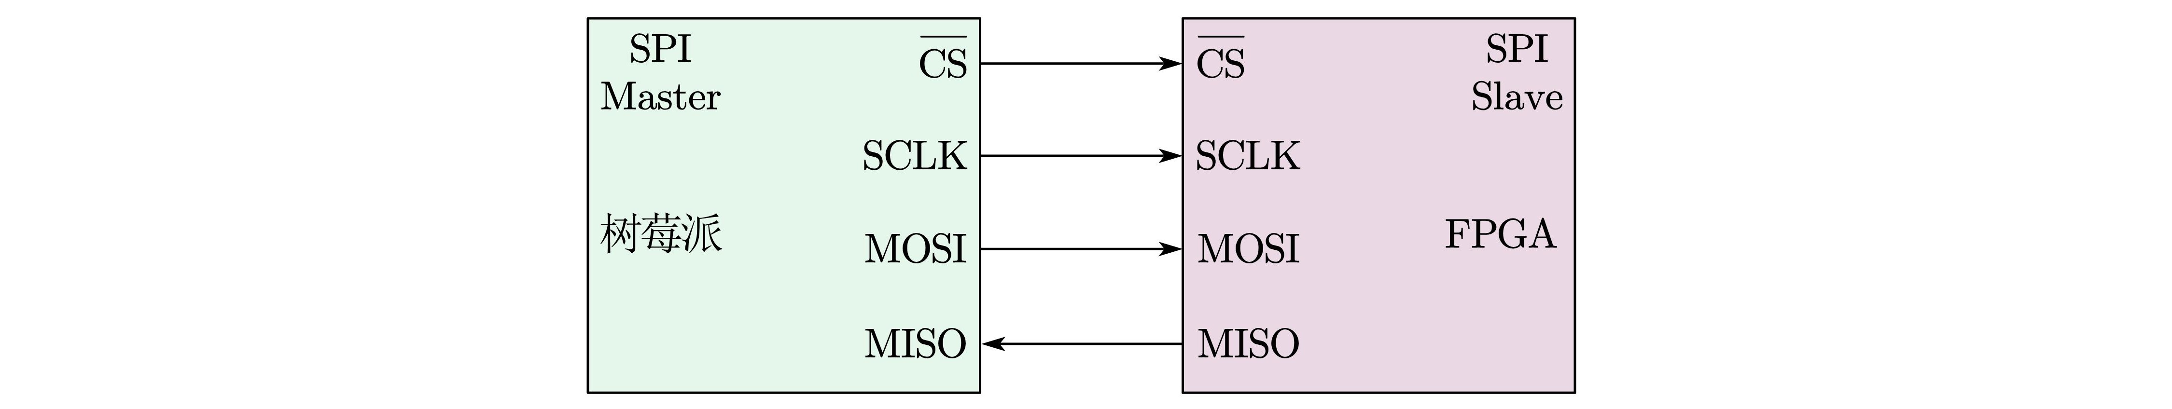
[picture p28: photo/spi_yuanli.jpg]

    
SPI（Serial Peripheral Interface，串行外围设备接口）是一种同步串行接口技术，
是一种高速、全双工、同步通信总线，在芯片中只占用四根管脚用来控制及数据传输。
SPI有四种工作时序，由以下两个参数控制：
+ CPOL：时钟极性选择，为0时SPI总线空闲为低电平，为1时SPI总线空闲为高电平
+ CPHA：时钟相位选择，为0时在SCK第一个跳变沿采样，为1时在SCK第二个跳变沿采样
      
本作品采用SPI模式1，即空闲时SCLK低电平，数据在SCLK下降沿被采样。
## 实现方法

### spi的实现
```python
# 导入wiringpi包
import wiringpi

# 使用spi[0]，最高速率设为15600000bit/s，spi时序使用模式1
wiringpi.wiringPiSPISetupMode(0, 15600000, 1)

# 向spi[0]发送两个字节，分别为1和15
wiringpi.wiringPiSPIDataRW(0, bytes([1, 15]))
```
上面是树莓派基于wiringpi-python实现通过spi发送两个字节1和15的程序

    
位于FPGA端的SPI从模块采用Altera现有的IP核实现，以加快开发速度。
树莓派每次向FPGA发送两个字节，FPGA需要自行拆开成为地址和数据，
注意到SPI从模块每次收完8bit数据都要在stsourcevalid输出一个正脉冲，
而数据的收发都在nss被拉低的条件下进行，于是设计了上图所示的状态转换图。     

    
仿真时序如上图所示，发送的两字节数据被拆开成了寄存器地址addr和数据data。      

### DDS的实现
FPGA将spi发来的信号拆开成地址和数据，然后把数据写入寄存器组对应的地址。     
|  address  | 内容 |
|  :----: | :----:  |
| 0 | 高四位代表占空比，低四位代表波形类型 |
| 1 | 频率控制字最低位（LSB）：inc_phi[7:0] |
| 2 | 频率控制字，inc_phi[15:8] |
| 3 | 频率控制字，inc_phi[23:16] |
| 4 | 频率控制字最高位（MSB），inc_phi[31:24] |
      
上表是寄存器组功能描述，表第二列的内容是第一列地址对应寄存器的功能。     
```python
def set_wave(self, f, d, w):
	self.f = f # f是从GUI传来的频率设置值
	self.d = d # d是占空比，d=0代表占空比设为6.25%，d=15代表占空比设为100%
	self.w = w # w是波形类型，w=0代表产生正弦波，w=1代表产生三角波，w=2代表产生锯齿波
	reg0 = ((self.d<<4) + self.w) & 255 # 地址为0的寄存器，被赋值d*16+w
	# K是GUI传来的频率控制字，DDS时钟100MHz，频率控制字位宽32位，2^32/100e6=42.95
	K = int(self.f * 2 ** 32 / 1e8) # 于是K等于频率f乘以42.95
	reg1 = (K>> 0) & 255 # reg1等于K的最低8位，与上表相符
	reg2 = (K>> 8) & 255 # reg2等于K的[15:8]位
	reg3 = (K>>16) & 255 # reg3等于K的[23:16]位
	reg4 = (K>>24) & 255 # reg4等于K的最高8位，与上表相符
	
	# 树莓派通过spi[0]向FPGA发送两个字节，分别为[0,reg0]到FPGA，被FPGA拆开成地址和数据，并存入寄存器组
	wiringpi.wiringPiSPIDataRW(0, bytes([0,reg0])) # 发送两个字节[0,reg0]到FPGA
	wiringpi.wiringPiSPIDataRW(0, bytes([1,reg1])) # 发送两个字节[1,reg1]到FPGA
	wiringpi.wiringPiSPIDataRW(0, bytes([2,reg2])) # 发送两个字节[2,reg2]到FPGA
	wiringpi.wiringPiSPIDataRW(0, bytes([3,reg3])) # 发送两个字节[3,reg3]到FPGA
	wiringpi.wiringPiSPIDataRW(0, bytes([4,reg4])) # 发送两个字节[4,reg4]到FPGA
```
用户操作树莓派上运行的GUI，并对信号发生器的频率、波形类型或占空比参数做更改后，
会执行上面的`self.set_wave(f,d,w)`函数，从而完成树莓派通过SPI接口向FPGA发送波形参数的过程。
FPGA随即根据SPI来的数据对DDS参数进行配置，实现本作品信号发生器功能的“所见即所得”。
### GUI的实现
QT是世界上最强大的GUI框架之一，pyqt5作为其在python的移植版本，
有着更高的开发效率和更低的开发难度，本作品的信号发生器GUI采用pyqt5框架。

    
上图就是pyqt5框架开发本作品的效果，需要指出的是，matplotlib可以作为一个模块嵌入到pyqt5中，
上图`波形预览`部分的波形图就是如此实现的。

下一部分，[软件篇--示波器设计与频率测量算法](https://github.com/lu1198373615/MonikaSystem/blob/master/OSCILLOSCOPE.md)     
      
上一部分，[硬件篇--自制FPGA开发板介绍](https://github.com/lu1198373615/MonikaSystem/blob/master/HARDWARE.MD)

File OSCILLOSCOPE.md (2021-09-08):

## 前言
本部分展示了波形显示和频率测量的效果图，并介绍原理和实现方法。约1100字，共24图。     

## 效果展示

    

    
鄙人把[介绍视频](https://www.bilibili.com/video/BV1644y1q7s1/) 放在了B站。     
视频拍摄场景：把本作品和树莓派合体后，DA输出端连接示波器，AD输入端接信号发生器，如上图所示。
用鼠标操作运行在树莓派的基于pyqt5的GUI程序，可以随意改变DA输出的波形，可以对信号发生器送入AD的信号进行显示和频率测量。     
### 波形显示功能

    

    

    
上图展示了：当信号发生器产生方波、正弦波和三角波时，树莓派GUI上正确显示出了波形。      
### Chirp-Z Transform实现频率测量

    

    

    

    

    

    

    
上图展示了：当信号发生器产生1MHz、1.5MHz、2MHz、2.5MHz、3MHz、3.5MHz正弦波时，
树莓派使用CZT算法正确测量频率并在GUI上显示出了频率测量结果。     
### 全相位FFT时移相位差频谱矫正法实现频率测量

    

    

    

    

    

    

    
上图展示了：当信号发生器产生2.123456MHz、2MHz、2.5MHz、3MHz、4MHz、4.5678954MHz正弦波时，
树莓派使用全相位FFT时移相位差频谱矫正法算法正确测量频率并在GUI上显示出了频率测量结果，且频率测量精度高于CZT。     

## 频率测量算法介绍

### CZT

_懒得介绍。。。_      
### apFFT

_懒得介绍。。。_      
请参考论文：[基于频移补偿的全相位时移相位差频率估计](https://kns.cnki.net/kcms/detail/detail.aspx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)       

## 原理介绍

### 总体原理

    
### 异步FIFO原理

    
树莓派采用非实时操作系统，GPIO速率较低且在为AD转换器提供时钟驱动时孔径抖动较大，
这一问题可通过异步FIFO解决。
上图展示了由FPGA提供与AD驱动时钟同步的时钟作为FIFO写时钟，
由树莓派GPIO提供FIFO读时钟的原理框图。
使用异步FIFO对AD采样数据做缓存可以解决时钟频率不匹配问题。
### 乒乓机制原理
乒乓机制是一种用空间换时间的方法，在处理内存A里数据的同时，把采集的数据存入内存B；
处理B时把采集的数据存入内存A。
### WSPI原理

    
上图是WSPI时序图。
我们知道，SPI传输协议抗干扰的设计思想是：被主机片选后，如果从机在DCLK的上升/下降沿将数据送出，
那么主机只会在DCLK的下降/上升沿，也就是数据稳定后进行采样。
但传统的SPI传输方式中，数据线MISO位宽只有1bit。
而本作品中采用的WSPI传输协议，数据线位宽12bit，这大大增加了传输带宽，且有着极低的误码率。

## 实现方法

### 乒乓机制在FPGA中的实现

    

    
上图是乒乓FIFO控制器的状态转换图和时序仿真结果。       

需要要注意的是：树莓派GPIO过来的信号是异步信号，需要向本时钟域同步。
这里采用的跨时钟域处理方法是使用两级D触发器消除亚稳态。       
[在pingpang_fifo.v文件中](https://github.com/lu1198373615/MonikaSystem/blob/master/code_in_quartus/MONIKA/pingpang_fifo.v)     
```verilog
//输入信号滤波--树莓派GPIO过来的信号是异步信号，需要向本时钟域同步
	reg w_cs_n_buf_one, w_cs_n;
	always @(posedge clk) begin
		w_cs_n_buf_one <= w_cs_n_input;
		w_cs_n <= w_cs_n_buf_one;
	end
	reg w_dclk_buf_one, w_dclk;
	always @(posedge clk) begin
		w_dclk_buf_one <= w_dclk_input;
		w_dclk <= w_dclk_buf_one;
	end
```

### WSPI在树莓派的实现
```python
# 从异步FIFO中读取point个数据
def fifo_sample(self,point):
	wiringpi.digitalWrite(self.w_cs_n,0)
	#time.sleep(0.1)
	result = []
	for i in range(0,point):
		wiringpi.digitalWrite(self.w_dclk,1)
		wiringpi.digitalWrite(self.w_dclk,0)
		ccc = wiringpi.digitalReadByte()
		#print(ccc)
		if ccc > (2 ** (self.ad_width - 1)) - 1:
            ccc = ccc - 2 ** self.ad_width
        result.append(ccc)
	wiringpi.digitalWrite(self.w_cs_n,1)
	#time.sleep(0.1)
	return result
```
在树莓派端的GUI使用pyqt5设置定时器，每2秒执行一次上面的`self.fifo_sample(point)`函数，
point代表每次从FIFO读取的数据个数，w_dclk是树莓派的某个GPIO，它直接连接到
FPGA中异步FIFO的读时钟处。在w_dclk的上升沿，数据被从FIFO读出，在wdclk的下降沿，
树莓派运行`wiringpi.digitalReadByte()`函数，从FPGA处读取数据，从而实现WSPI的时序。
+ 需要指出的是，这里的`wiringpi.digitalReadByte()`函数需要稍作修改：[修改说明](https://github.com/lu1198373615/MonikaSystem/blob/master/MODIFY.md)。      

上一部分，[软件篇--“所见即所得”的任意波形发生器设计](https://github.com/lu1198373615/MonikaSystem/blob/master/SIGNALGENERATOR.md)

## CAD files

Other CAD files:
code_in_quartus/MONIKA/stp1.stp

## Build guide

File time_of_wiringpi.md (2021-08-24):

## 树莓派GPIO速度
目前最受欢迎的操作树莓派GPIO的方式是使用wiringPi软件包，
[热心网友已经证明](https://blog.csdn.net/a897180673/article/details/77976053/)，
wiringPi相比于其他方式，操作GPIO时速度更快。     
本文以上为基础，进一步测试树莓派GPIO极限性能。      
+ 平台：树莓派4B，8G内存版
+ 语言：c和python
+ 软件包：wiringPi、wiringPi-python

## c语言版

### 程序
```c
#include <wiringPi.h>
#include <stdio.h>
#include <time.h>

int main (void) {
	int repeat_time = 27000000;//循环次数可配置
	clock_t start, finish;
	double Total_time;
	wiringPiSetup();
	pinMode(0, INPUT);
	start = clock();
	for (int i=0;i<repeat_time;i++) {
		digitalWrite(0,1);
		digitalWrite(0,0);
	}
	finish = clock();
	Total_time = (double)(finish-start) / CLOCKS_PER_SEC;
    printf( "%f seconds\n", Total_time);
	return 0;
}
```
### 结果

     
循环repeat_time = 1 000 000 时，运行时间为0.055038秒      

     
循环repeat_time = 27 000 000 时，运行时间为1.007372秒      
如果把for循环改为while循环，不再需要计算和比较i值，说不定速度可以更快，
但那需要用示波器查看频率，所以暂时就不测了。       

## python语言版

### 单个GPIO
```python
import wiringpi
import time

wiringpi.wiringPiSetup()
wiringpi.pinMode(0, 0)

start = time.perf_counter()
for i in range(1000000):
    wiringpi.digitalWrite(0,1)
    wiringpi.digitalWrite(0,0)

print(time.perf_counter() - start)
```

     
竟然需要1.689秒，看来python慢可不仅是传说而已，相比之下c语言只需要0.055038秒啊。      

### WSPI读FIFO程序
本文之前说过，波形显示功能从FPGA读数据使用WSPI，那么WSPI能达到多少速度呢？     
```python
from MyWSPI import *

w = MyWSPI()

repeat_time = 10000 # 循环次数可配置

start = time.perf_counter()
y = w.fifo_sample(repeat_time)
print(time.perf_counter() - start)
```

     
上图是把repeat_time分别设置为10000和1000000时的运行结果，用时分别为0.029和2.937秒。

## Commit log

2021-07-12 完结，撒花~~~
    [MONIKA.DSN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]
2021-09-05 洗了一下代码
    [stp1.stp]
